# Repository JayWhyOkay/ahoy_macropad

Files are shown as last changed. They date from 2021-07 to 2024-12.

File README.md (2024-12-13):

# Ahoy -- XT Macropad

Complete Project

Ahoy is a simple but functional macropad designed for people who need both a numpad and a macro column for work/productivity. The features include:

- Numpad with split mod support
- 10 additional keys for macros
- Rotary encoder support on top left key
- 8 addressable RGB LEDs 
- Num, Caps, Scroll Lock Indicator LEDs
- USB C (USB 2.0)

The layout for the macropad can be seen below: 

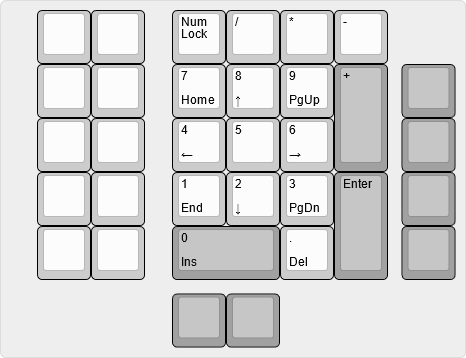
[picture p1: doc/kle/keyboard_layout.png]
Layout example


## Instructions
To replicate the PCB and the case, the guide can be found below: 
- [Instructions on ordering this PCB](ahoy_pcb/gerber/production/)
- [Instructions on ordering the case](acrylic_case/)

## Project Status
- [x] Design PCB
- [x] Design Case
- [x] Order Prototypes
- [x] Create bootloader
- [x] Create QMK/VIA firmware
- [x] Revise prototypes
### Todo List
- [x] Revise LED cutouts on acrylic case 
- [ ] \(Optional) add art/silkscreen
- [ ] Clear @todo 's
- [ ] Update to modern QMK standards!
## Licensing 
The following project was built on Gondolindrim's [Acheron Project](https://github.com/AcheronProject) and ai03's [PCB guide](https://wiki.ai03.com/books/pcb-design/chapter/pcb-designer-guide) and [design files](https://github.com/ai03-2725). As such, the licensing will follow their licensing arrangement on top of this project's licensing, which can be found [here](LICENSE).

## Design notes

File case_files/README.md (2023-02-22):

# Ahoy Macropad Case

Included in this are two options for cases, a 3D printed case and an acrylic case. 

Rough guidelines and materials required are listed in each folder.

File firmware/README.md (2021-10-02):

# Ahoy Macropad Firmware

To flash the keyboard, please use QMK Toolbox or other flashing tools to flash an Atmega32U4. The bootloader is based off the factory-based Atmel-DFU.

The firmware is VIA compatible.

To load the board into VIA, enable the "Design" tab in your VIA program, then load the JSON file in VIA.

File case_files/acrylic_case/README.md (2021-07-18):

# Ahoy Macropad Acrylic Casing
This section is to order a case if you happen to stumble/own a PCB for this. 

The case consists of stacked acrylic pieces that combine together to make the final product.

The design files were ordered from [Ponoko](https://www.ponoko.com/), which, in my experience, is one of the cheaper places to order laser cut acrylic pieces on demand in low quantity. 

## Parts, dimensions, thickness (from bottom to top)
In order to order this case, you will need to source the following:
- 1x ahoy_bottom - *135.8mm x 107.2mm* - **3mm thickness acrylic (CLEAR, FROSTED, OR OPAL for the RGB underglow)**
- 1x ahoy_mid_1 - *135.8mm x 107.2mm* - **3mm thickness acrylic (CLEAR, FROSTED, OR OPAL for the RGB underglow)**
- 1x ahoy_mid_2 - *135.8mm x 107.2mm* - **3mm thickness acrylic**
- 1x ahoy_plate - *135.8mm x 107.2mm* - **3mm thickness acrylic**
- 2x ahoy_top (for high profile look) - *135.8mm x 107.2mm* - **3mm thickness acrylic**

### Screws and other components
- 6x M2.5 Screws 
    - for a high-profile look, source 20mm length screws 
    - for a low-profile look (no *ahoy_top* pieces), source 14mm length screws

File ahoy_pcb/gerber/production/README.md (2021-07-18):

# Ahoy Macropad PCB Production Guide
The following brief instructions are for JLCPCB, and the instructions are formatted for JLCPCB Guidelines

## Instructions
1. Navigate to [JLCPCB](https://jlcpcb.com/)
2. Upload the *ahoy_pcb-gerber.zip* file
    - Keep most specifications in default (unless you know what you are doing)
    - The following can be changed to your preference:
        - PCB Color (only green or black)
        - Quantity
        - Remove Order Number
    - @todo add full specifications 
3. Enable SMT Assembly
    - Be sure to follow JLCPCB SMT guidelines
    - Choose "Assemble bottom side" 
    - For now, select "Added by JLCPCB" for the tooling holes. 
        - This will be changed in a future revision of the PCB
4. After clicking next, upload the *ahoy-pcb-bom.xlsx* BOM file in the BOM prompt and the *ahoy_pcb-bottom-pos.csv* CPL file in the CPL Prompt. 
5. After clicking next, validate the parts chosen. Validate that 17 parts are confirmed. 
    - @todo add BOM list in REDME
6. After validating, save to cart and order

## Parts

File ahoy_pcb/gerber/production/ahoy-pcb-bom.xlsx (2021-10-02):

Comment | Designator | Footprint | LCSC Part #（optional）
22pF | C1, C2 | 0805 | C1804
1uF | C3 | 0805 | C28323
0.1uF | C4, C5, C6, C16 | 0805 | C49678
10uF | C7, C8, C9, C10, C11, C12, C13, C14, C15 | 0805 | C15850
D_SOD-123 Diode | D1, D2, D3, D4, D5, D6, D7, D8, D9, D10, D11, D12, D13, D14, D15, D16, D17, D18, D19, D20, D21, D22, D23, D24, D25, D26, D27, D28, D29, D30 | SOD-123 | C81598
Polyfuse, 500mA hold, 1A trip | F1 | 1206 | C70076
Resistor 22 | R1, R2 | 0805 | C17561
Resistor 10K | R3, R4 | 0805 | C17414
Resistor 5.1K | R5, R6 | 0805 | C27834
Resistor 2K | R7, R8, R9 | 0805 | C17513
Resistor 470 | R10 | 0805 | C17710
Low profile switch | SW1 | SMD-SW-4_5.1x5.1x1.5 | C318884
ATmega32u4-A | U1 | TQFP-44_10.0x10.0x0.8P | C44854
USB ESD protection | U2 | SOT-23-6L | C7519
USB Type C Receptacle | J1 | TYPE-C-31_L8.94_W7.3 | C165948
16MHz Crystal | Y1 | SMD-3225_4P

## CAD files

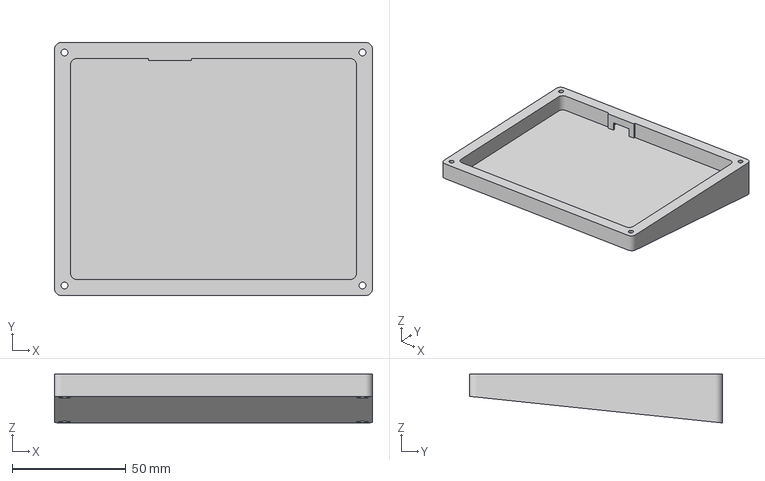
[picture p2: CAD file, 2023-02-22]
case_files/3d_printed_case/Bottom.3mf
139.8 x 111.2 x 21.5 mm

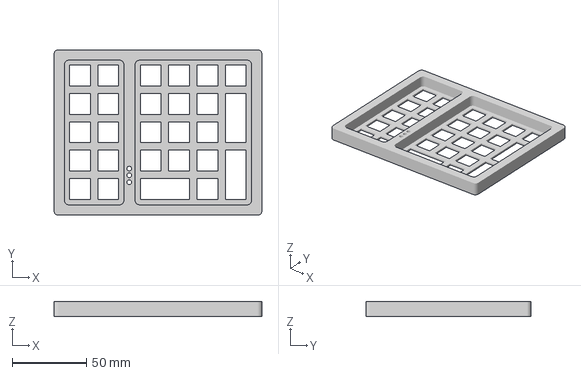
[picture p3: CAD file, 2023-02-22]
case_files/3d_printed_case/Ahoy 3D Print Top V2.3mf
139.8 x 111.2 x 10.0 mm

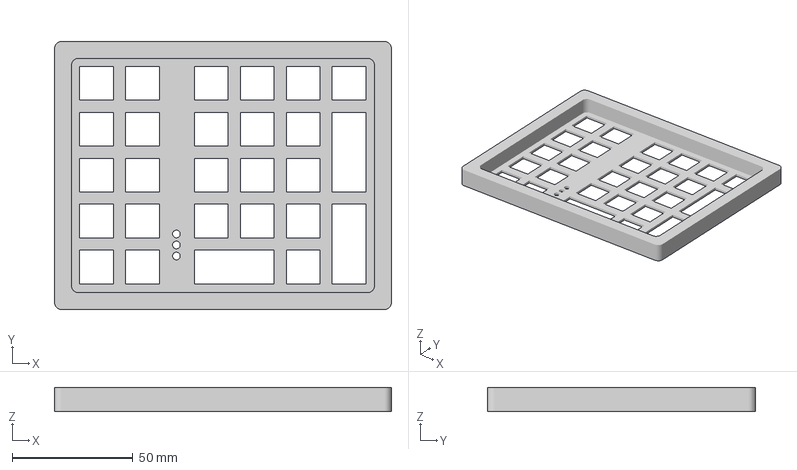
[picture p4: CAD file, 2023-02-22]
case_files/3d_printed_case/Top.3mf
139.8 x 111.2 x 10.0 mm

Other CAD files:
case_files/acrylic_case/ahoy_top_rev2.dxf
case_files/acrylic_case/ahoy_mid_1_rev2.dxf
case_files/3d_printed_case/Ahoy 3D Print Bottom V2.3mf
case_files/acrylic_case/ahoy_bottom_rev2.dxf
case_files/acrylic_case/ahoy_plate_rev2.dxf
case_files/acrylic_case/ahoy_mid_2_rev2.dxf
case_files/acrylic_case/ahoy_master_template.dwg
case_files/acrylic_case/ahoy_bottom_rev2.dwg
case_files/acrylic_case/ahoy_mid_1_rev2.dwg
case_files/acrylic_case/ahoy_mid_2_rev2.dwg
case_files/acrylic_case/ahoy_plate_rev2.dwg
case_files/acrylic_case/ahoy_top_rev2.dwg

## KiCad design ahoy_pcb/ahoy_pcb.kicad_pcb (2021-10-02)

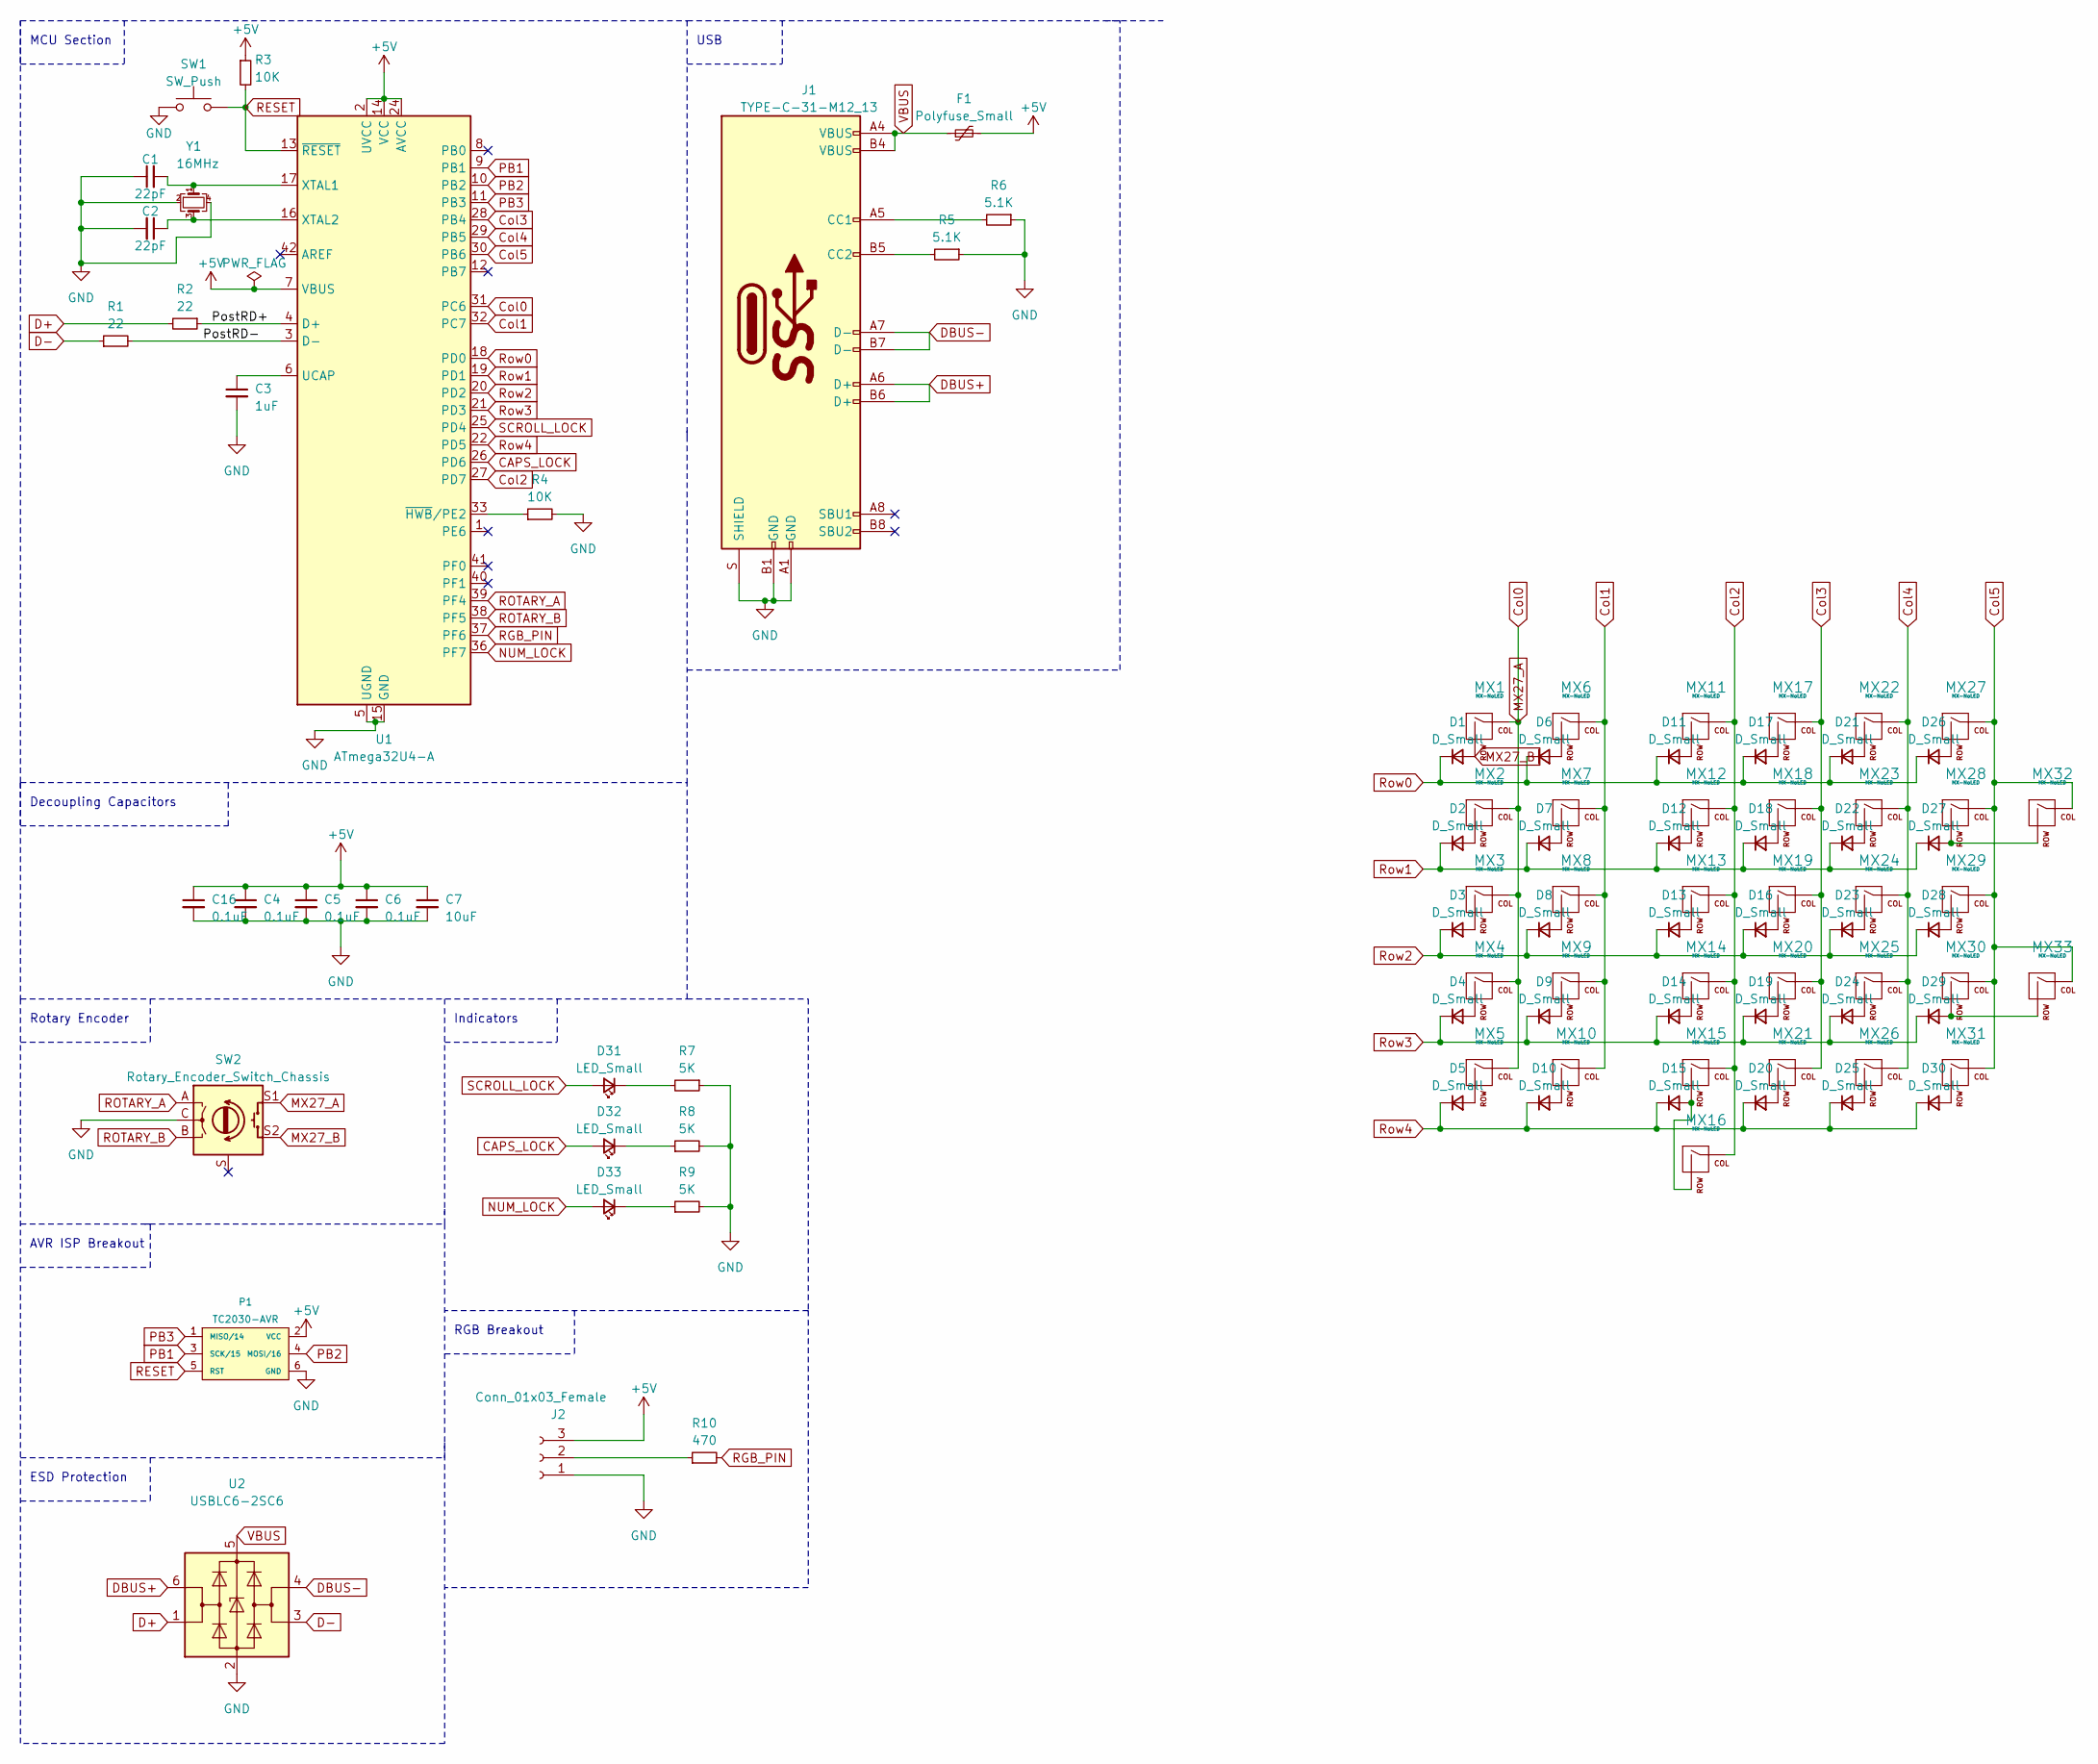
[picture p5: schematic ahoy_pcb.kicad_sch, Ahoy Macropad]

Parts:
C1, C2: 22pF; C_0805_2012Metric
C3: 1uF; C_0805_2012Metric
C4, C5, C6, C16: 0.1uF; C_0805_2012Metric
C7: 10uF; C_0805_2012Metric
D1, D2, D3, D4, D5, D6, D7, D8, D9, D10, D11, D12, D13, D14, D15, D16, D17, D18, D19, D20, D21, D22, D23, D24, D25, D26, D27, D28, D29, D30: D_Small; D_SOD-123
D31, D32, D33: LED_Small; LED_D3.0mm-Pretty
F1: Polyfuse_Small; Fuse_1206_3216Metric
J1: TYPE-C-31-M12_13; TYPE-C-31-M-12
J2: Conn_01x03_Female; PinHeader_1x3_staggered_P2.54mm_Vertical
MX1, MX2, MX3, MX4, MX5, MX6, MX7, MX8, MX9, MX10, MX11, MX12, MX13, MX14, MX15, MX17, MX18, MX19, MX20, MX21, MX22, MX23, MX24, MX25, MX26, MX27, MX28, MX29, MX30, MX31: MX-NoLED; MXOnly-1U-NoLED
MX16, MX32, MX33: MX-NoLED; MXOnly-2U-ReversedStabilizers-NoLED
P1: TC2030-AVR; PinHeader_2x3_P2.54mm_Vertical
R1, R2: 22; R_0805_2012Metric
R3, R4: 10K; R_0805_2012Metric
R5, R6: 5.1K; R_0805_2012Metric
R7, R8, R9: 5K; R_0805_2012Metric
R10: 470; R_0805_2012Metric
SW1: SW_Push; SW_TS-1187A-B-A-B
SW2: Rotary_Encoder_Switch_Chassis; RotaryEncoder_Alps_EC11E-Switch_Vertical_H20mm_CircularMoun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
U1: ATmega32U4-A; TQFP-44_10x10mm_P0.8mm
U2: USBLC6-2SC6; SOT-23-6
Y1: 16MHz; Crystal_SMD_3225-4Pin_3.2x2.5mm

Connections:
+5V: C4.1, C5.1, C6.1, C7.1, C16.1, F1.2, J2.3, P1.2 (VCC), R3.1, U1.2 (UVCC), U1.7 (VBUS), U1.14 (VCC), U1.24 (AVCC), U1.34 (VCC), U1.44 (AVCC)
/PostRD+: R2.1, U1.4 (D+)
/PostRD-: R1.2, U1.3 (D-)
CAPS_LOCK: D32.2 (A), U1.26 (PD6)
Col0: MX1.1 (COL), MX2.1 (COL), MX3.1 (COL), MX4.1 (COL), MX5.1 (COL), SW2.S1, U1.31 (PC6)
Col1: MX6.1 (COL), MX7.1 (COL), MX8.1 (COL), MX9.1 (COL), MX10.1 (COL), U1.32 (PC7)
Col2: MX11.1 (COL), MX12.1 (COL), MX13.1 (COL), MX14.1 (COL), MX15.1 (COL), MX16.1 (COL), U1.27 (PD7)
Col3: MX17.1 (COL), MX18.1 (COL), MX19.1 (COL), MX20.1 (COL), MX21.1 (COL), U1.28 (PB4)
Col4: MX22.1 (COL), MX23.1 (COL), MX24.1 (COL), MX25.1 (COL), MX26.1 (COL), U1.29 (PB5)
Col5: MX27.1 (COL), MX28.1 (COL), MX29.1 (COL), MX30.1 (COL), MX31.1 (COL), MX32.1 (COL), MX33.1 (COL), U1.30 (PB6)
D+: R2.2, U2.1 (I/O1)
D-: R1.1, U2.3 (I/O2)
DBUS+: J1.A6 (D+), J1.B6 (D+), U2.6 (I/O1)
DBUS-: J1.A7 (D-), J1.B7 (D-), U2.4 (I/O2)
GND: C1.1, C2.2, C3.2, C4.2, C5.2, C6.2, C7.2, C16.2, J1.A1 (GND), J1.B1 (GND), J1.S (SHIELD), J2.1, P1.6 (GND), R4.2, R5.1, R6.1, R7.1, R8.2, R9.2, SW1.1, SW2.C, U1.5 (UGND), U1.15 (GND), U1.23 (GND), U1.35 (GND), U1.43 (GND), U2.2 (GND), Y1.2, Y1.4
MX27_B: D1.2 (A), MX1.2 (ROW), SW2.S2
NUM_LOCK: D33.2 (A), U1.36 (PF7)
unnamed: C1.2, U1.17 (XTAL1), Y1.1
unnamed: C2.1, U1.16 (XTAL2), Y1.3
unnamed: C3.1, U1.6 (UCAP)
unnamed: D2.2 (A), MX2.2 (ROW)
unnamed: D3.2 (A), MX3.2 (ROW)
unnamed: D4.2 (A), MX4.2 (ROW)
unnamed: D5.2 (A), MX5.2 (ROW)
unnamed: D6.2 (A), MX6.2 (ROW)
unnamed: D7.2 (A), MX7.2 (ROW)
unnamed: D8.2 (A), MX8.2 (ROW)
unnamed: D9.2 (A), MX9.2 (ROW)
unnamed: D10.2 (A), MX10.2 (ROW)
unnamed: D11.2 (A), MX11.2 (ROW)
unnamed: D12.2 (A), MX12.2 (ROW)
unnamed: D13.2 (A), MX13.2 (ROW)
unnamed: D14.2 (A), MX14.2 (ROW)
unnamed: D15.2 (A), MX15.2 (ROW), MX16.2 (ROW)
unnamed: D16.2 (A), MX19.2 (ROW)
unnamed: D17.2 (A), MX17.2 (ROW)
unnamed: D18.2 (A), MX18.2 (ROW)
unnamed: D19.2 (A), MX20.2 (ROW)
unnamed: D20.2 (A), MX21.2 (ROW)
unnamed: D21.2 (A), MX22.2 (ROW)
unnamed: D22.2 (A), MX23.2 (ROW)
unnamed: D23.2 (A), MX24.2 (ROW)
unnamed: D24.2 (A), MX25.2 (ROW)
unnamed: D25.2 (A), MX26.2 (ROW)
unnamed: D26.2 (A), MX27.2 (ROW)
unnamed: D27.2 (A), MX28.2 (ROW), MX32.2 (ROW)
unnamed: D28.2 (A), MX29.2 (ROW)
unnamed: D29.2 (A), MX30.2 (ROW), MX33.2 (ROW)
unnamed: D30.2 (A), MX31.2 (ROW)
unnamed: D31.1 (K), R7.2
unnamed: D32.1 (K), R8.1
unnamed: D33.1 (K), R9.1
unnamed: J1.A5 (CC1), R6.2
unnamed: J1.B5 (CC2), R5.2
unnamed: R4.1, U1.33 (~HWB~/PE2)
unnamed: J2.2, R10.1
PB1: P1.3 (SCK/15), U1.9 (PB1)
PB2: P1.4 (MOSI/16), U1.10 (PB2)
PB3: P1.1 (MISO/14), U1.11 (PB3)
RESET: P1.5 (RST), R3.2, SW1.2, U1.13 (~RESET)
RGB_PIN: R10.2, U1.37 (PF6)
ROTARY_A: SW2.A, U1.39 (PF4)
ROTARY_B: SW2.B, U1.38 (PF5)
Row0: D1.1 (K), D6.1 (K), D11.1 (K), D17.1 (K), D21.1 (K), D26.1 (K), U1.18 (PD0)
Row1: D2.1 (K), D7.1 (K), D12.1 (K), D18.1 (K), D22.1 (K), D27.1 (K), U1.19 (PD1)
Row2: D3.1 (K), D8.1 (K), D13.1 (K), D16.1 (K), D23.1 (K), D28.1 (K), U1.20 (PD2)
Row3: D4.1 (K), D9.1 (K), D14.1 (K), D19.1 (K), D24.1 (K), D29.1 (K), U1.21 (PD3)
Row4: D5.1 (K), D10.1 (K), D15.1 (K), D20.1 (K), D25.1 (K), D30.1 (K), U1.22 (PD5)
SCROLL_LOCK: D31.2 (A), U1.25 (PD4)
VBUS: F1.1, J1.A4 (VBUS), J1.B4 (VBUS), U2.5 (VBUS)

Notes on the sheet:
MCU Section
Decoupling Capacitors
Rotary Encoder
AVR ISP Breakout
ESD Protection
Indicators
RGB Breakout
USB

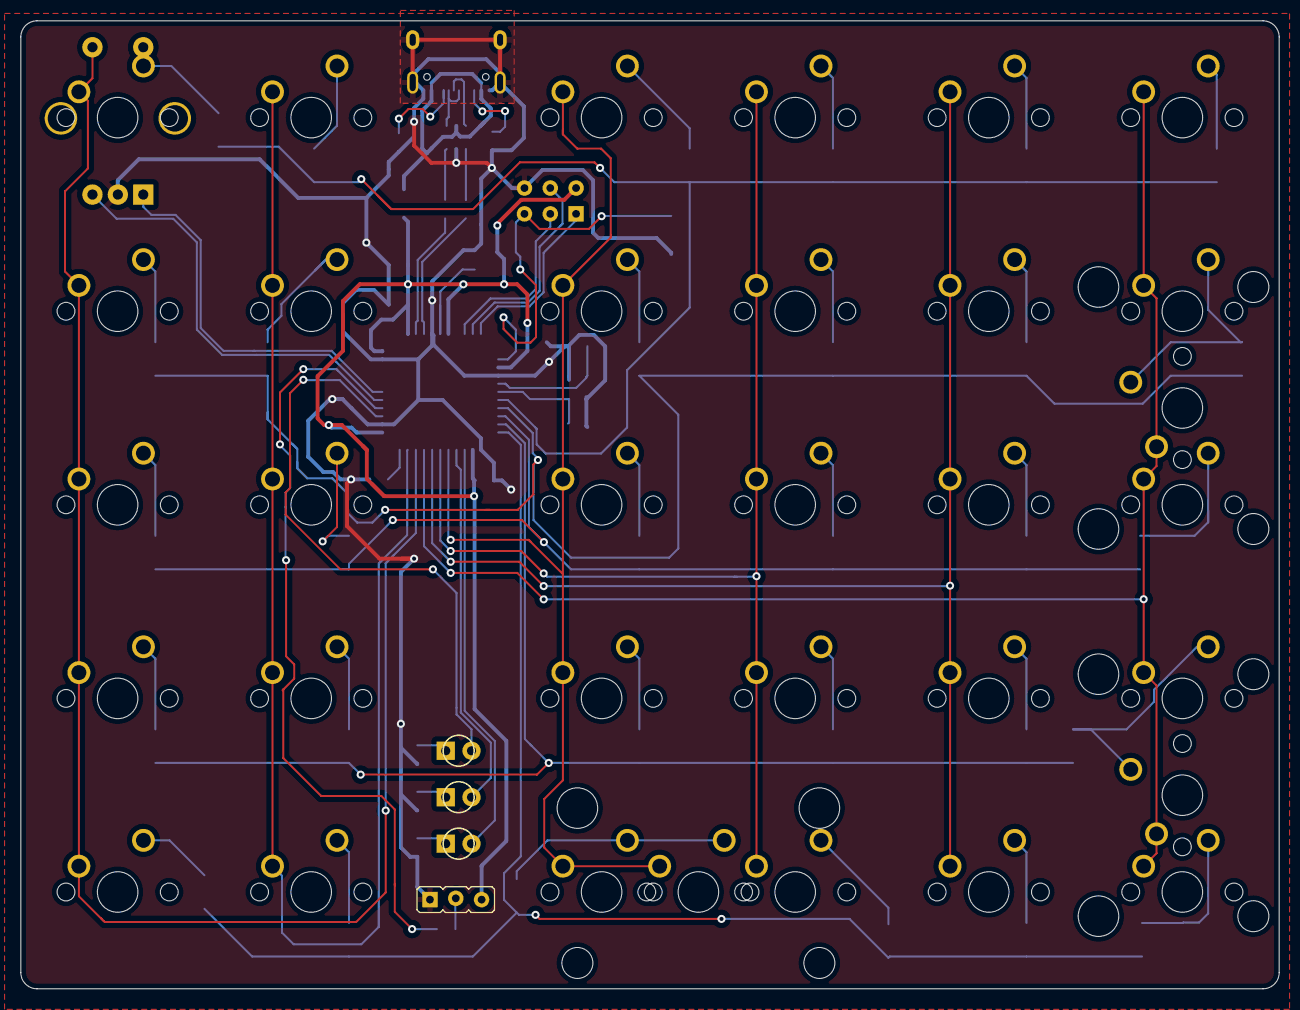
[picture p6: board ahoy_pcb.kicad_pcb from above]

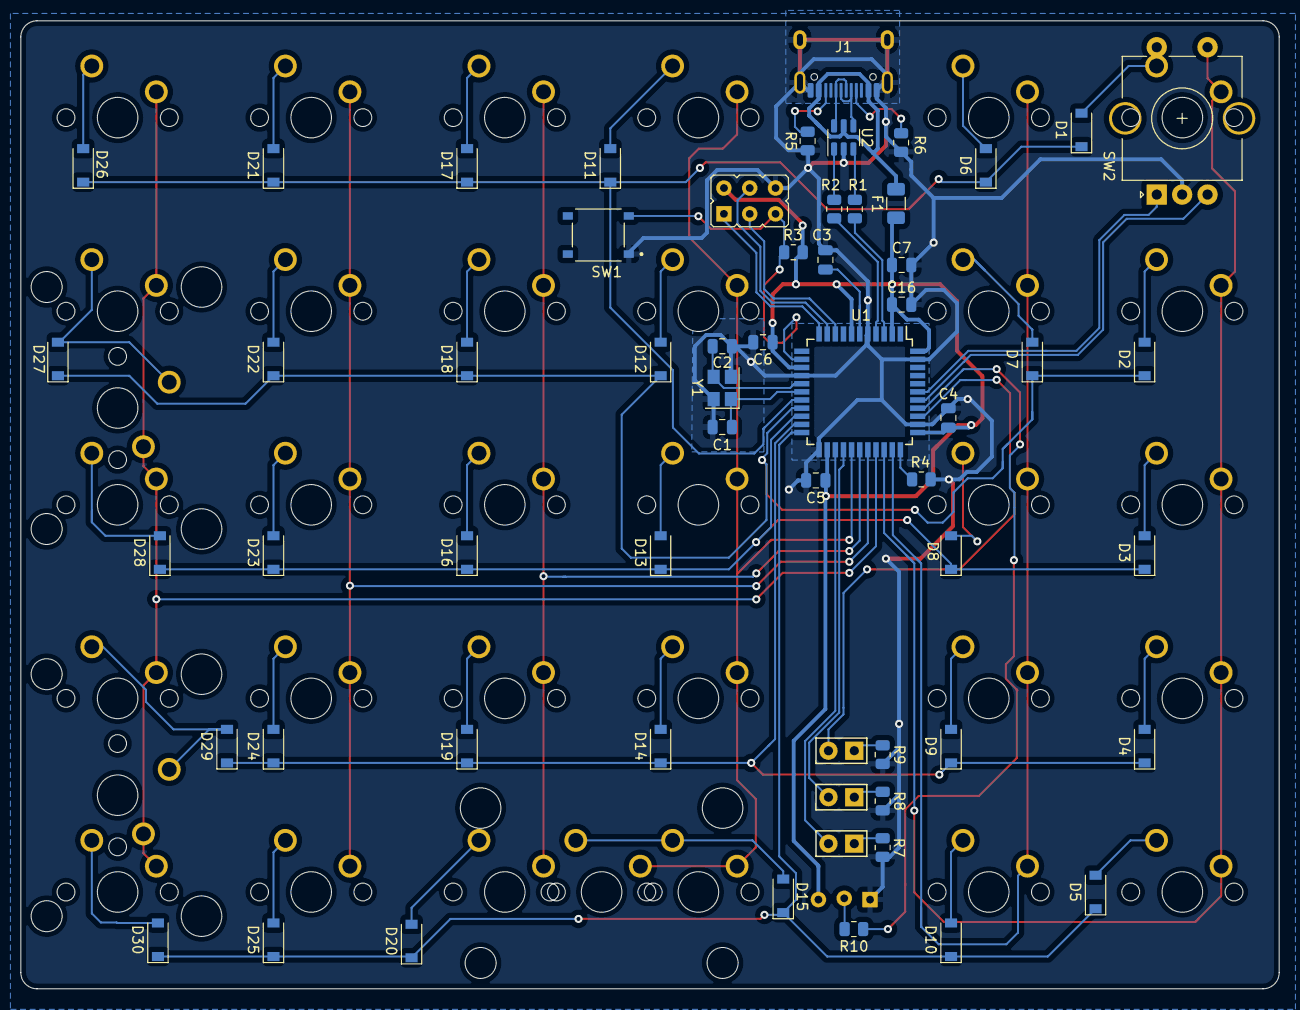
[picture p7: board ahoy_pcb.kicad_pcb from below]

Board: 2 copper layers, 123.8 x 95.2 mm, 93 parts (56 on the bottom side), 70 nets.

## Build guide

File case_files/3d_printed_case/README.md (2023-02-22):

# Ahoy Macropad 3D Printed Case

The 3D Printed case is included for those that have access to a 3D printer and want to avoid the higher costs of sourcing acrylic for laser cutting. 

The top half includes an integrated plate for the switches and PCB. The bottom half is angled for a smoother typing experience. 

## Instructions

### Print Settings 

Print both the top and bottom files using the slicer and filament of your choice. 

The print settings should be based off your printer and filament. PLA and ASA were tested with sufficient results. 

Post processing of print lines on the bottom half is optional, but recommended for a smooth fit between the top and bottom half.

### Assembly

In the top piece, there are 4 holes in the corners. These are intended for brass threaded inserts. 

The inserts specs are the following:
- Thread size: M3
- Length: 5mm
- Outer Diameter: 5.2mm 
- Pitch: 0.5mm (this shouldnt matter)

4 M3x8mm screws should then be used to screw the top and bottom half together.

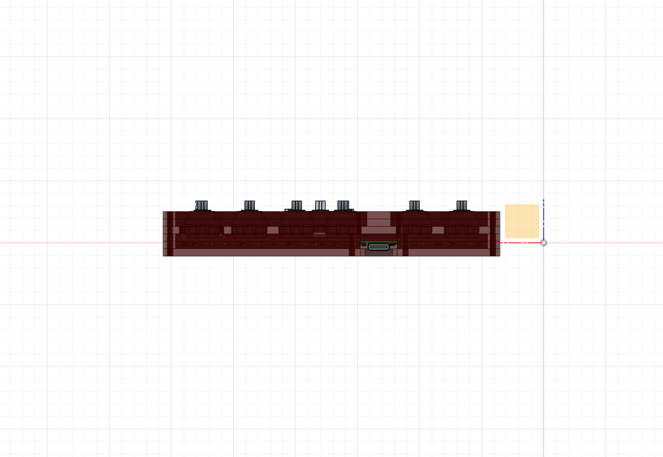
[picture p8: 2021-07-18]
doc/full_assembly_model_cutout.png

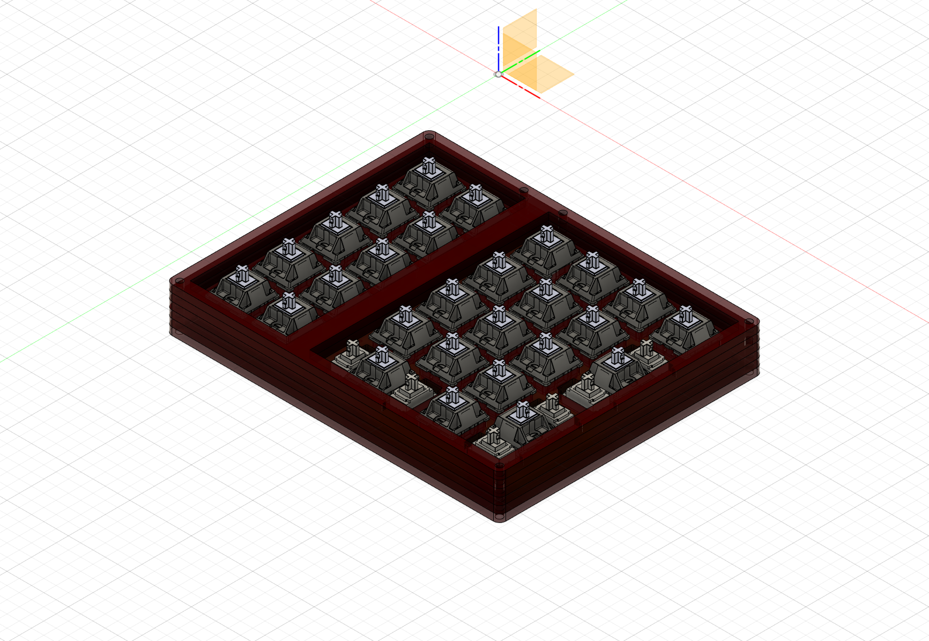
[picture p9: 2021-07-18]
doc/full_assembly_model.png

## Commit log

2021-07-18 Rev 1 Update
    [ahoy-pcb-bom.xlsx, ahoy_bottom_rev2.dwg, ahoy_bottom_rev2.dxf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]
2021-10-02 More updates
    [ahoy-pcb-bom.xlsx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]
2023-02-22 Final-Ish Commit
    [Ahoy 3D Print Bottom V2.3mf, Ahoy 3D Print Top V2.3mf, Bottom.3mf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]
